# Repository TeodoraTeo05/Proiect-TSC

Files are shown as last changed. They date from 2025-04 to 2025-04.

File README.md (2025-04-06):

# Proiect TSC 2025 – OpenBook

## Descriere generală

OpenBook este un dispozitiv portabil de tip e-book reader bazat pe ESP32-C6. Dispozitivul conține un ecran e-paper, butoane de control, senzor de mediu, ceas de timp real și posibilitate de alimentare de la baterie Li-Po, fiind gândit ca un sistem eficient energetic și scalabil.
---

#### 1 Diagramă bloc

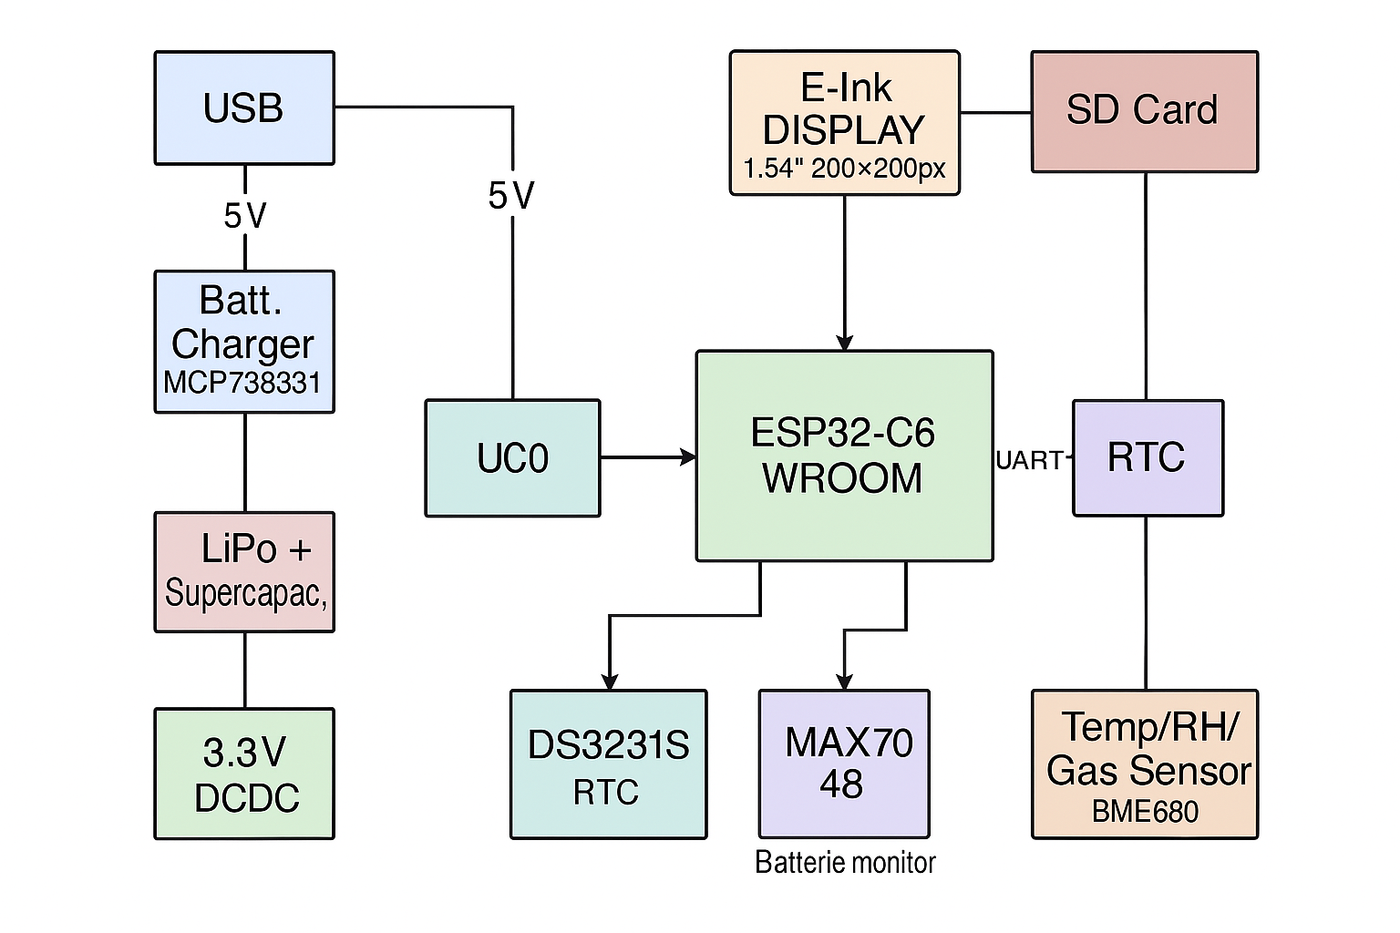
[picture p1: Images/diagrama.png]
Diagramă bloc


---
## 2 BOM (Bill of Materials)

| Part | Device | Datasheet |
|---|---|---|
| CHG_LED | ADAFRUIT_LEDCHIP-LED0603 | [ADAFRUIT_LEDCHIP-LED0603](N/A) |
| SJ1 | SJ | [SJ](N/A) |
| EPD_C5 | EAGLE-LTSPICE_CC0402 | [EAGLE-LTSPICE_CC0402](N/A) |
| R3 | ESP32_WROVER_EAGLE-LTSPICE_RR0402 | [ESP32_WROVER_EAGLE-LTSPICE_RR0402](N/A) |
| R1_PWRUSB | ESP32_WROVER_EAGLE-LTSPICE_RR0402 | [ESP32_WROVER_EAGLE-LTSPICE_RR0402](N/A) |
| C4_USB | EAGLE-LTSPICE_CC0402 | [EAGLE-LTSPICE_CC0402](N/A) |
| C1, C2, C6, C8, C9, C10, C_DELAY | ESP32_WROVER_EAGLE-LTSPICE_CC0402 | [ESP32_WROVER_EAGLE-LTSPICE_CC0402](N/A) |
| C3 | RCL_CPOL-EUCT3528 | [RCL_CPOL-EUCT3528](N/A) |
| R1, R1_PINH, R1_PINH1, R2_PINH, R2_PINH1, R4, R5, R6, R7, R8, R9, R10, R_BOOT, R_CHANGE, R_CL1, R_RESET | ESP32_WROVER_EAGLE-LTSPICE_RR0402 | [ESP32_WROVER_EAGLE-LTSPICE_RR0402](N/A) |
| C7 | ESP32_WROVER_EAGLE-LTSPICE_CC0402 | [ESP32_WROVER_EAGLE-LTSPICE_CC0402](N/A) |
| J4 | 112A-TAAR-R03_ATTEND | [112A-TAAR-R03_ATTEND](N/A) |
| R_CAPACITOR | ESP32_WROVER_EAGLE-LTSPICE_RR0402 | [ESP32_WROVER_EAGLE-LTSPICE_RR0402](N/A) |
| C5 | ESP32_WROVER_EAGLE-LTSPICE_CC0402 | [ESP32_WROVER_EAGLE-LTSPICE_CC0402](N/A) |
| EPD_C6, EPD_C7, EPD_C8, EPD_C9, EPD_C10, EPD_C11, EPD_C12 | EAGLE-LTSPICE_CC0402 | [EAGLE-LTSPICE_CC0402](N/A) |
| EPD_C1, EPD_C2 | ESP32_WROVER_EAGLE-LTSPICE_CC0402 | [ESP32_WROVER_EAGLE-LTSPICE_CC0402](N/A) |
| R2 | ESP32_WROVER_EAGLE-LTSPICE_RR0402 | [ESP32_WROVER_EAGLE-LTSPICE_RR0402](N/A) |
| R1_BAT | ESP32_WROVER_EAGLE-LTSPICE_RR0402 | [ESP32_WROVER_EAGLE-LTSPICE_RR0402](N/A) |
| Q1, Q2 | ESP32_WROVER_SPARKFUN-DISCRETESEMI_MOSFET_PCH-DMG2305UX-7 | [ESP32_WROVER_SPARKFUN-DISCRETESEMI_MOSFET_PCH-DMG2305UX-7](N/A) |
| R2_BAT | ESP32_WROVER_EAGLE-LTSPICE_RR0402 | [ESP32_WROVER_EAGLE-LTSPICE_RR0402](N/A) |
| C5_USB | EAGLE-LTSPICE_CC0402 | [EAGLE-LTSPICE_CC0402](N/A) |
| C1_BAT, C1_BAT1, C1_BAT2, C2_BAT | ESP32_WROVER_EAGLE-LTSPICE_CC0402 | [ESP32_WROVER_EAGLE-LTSPICE_CC0402](N/A) |
| C4 | ESP32_WROVER_EAGLE-LTSPICE_CC0402 | [ESP32_WROVER_EAGLE-LTSPICE_CC0402](N/A) |
| R2-USB, R2-USB1 | ESP32_WROVER_EAGLE-LTSPICE_RR0402 | [ESP32_WROVER_EAGLE-LTSPICE_RR0402](N/A) |
| L1 | 744043680IND_4828-WE-TPC_WRE | [744043680IND_4828-WE-TPC_WRE](N/A) |
| IC1 | BD5229G-TR | [BD5229G-TR](N/A) |
| SENSOR2 | ESP32_WROVER_BME680_BME680 | [ESP32_WROVER_BME680_BME680](N/A) |
| U$2 | BUTTON_CUSYOMV1 | [BUTTON_CUSYOMV1](N/A) |
| U$3 | BUTTON_CUSYOMV1 | [BUTTON_CUSYOMV1](N/A) |
| C10_SUPERCAP | CPH3225A | [CPH3225A](https://www.snapeda.com/parts/CPH3225A/Seiko+Instruments/view-part/?ref=snap) |
| U3 | DS3231SN# | [DS3231SN#](https://www.snapeda.com/parts/DS3231SN%23/Analog+Devices/view-part/?ref=snap) |
| U2 | ESP32-C6-WROOM-1-N8 | [ESP32-C6-WROOM-1-N8](N/A) |
| PFMF.050.1 | ESP32C6_VARISTORCN1812 | [ESP32C6_VARISTORCN1812](N/A) |
| D2, D7 | ESP32_WROVER_AVX---SD0805S020S1R0_AVX_SD0805S020S1R0_0_0AVX_SD0805S020S1R0_0_0 | [ESP32_WROVER_AVX---SD0805S020S1R0_AVX_SD0805S020S1R0_0_0AVX_SD0805S020S1R0_0_0](N/A) |
| MCP73831 | ESP32_WROVER_SPARKFUN-IC-POWER_MCP73831 | [ESP32_WROVER_SPARKFUN-IC-POWER_MCP73831](N/A) |
| J1 | FH34SRJ-24S-0.5SH_99_ | [FH34SRJ-24S-0.5SH_99_](N/A) |
| U4 | MAX17048G+T10 | [MAX17048G+T10](https://www.snapeda.com/parts/MAX17048G+T10/Analog+Devices/view-part/?ref=snap) |
| D3, D4, D5 | MBR0530 | [MBR0530](https://www.snapeda.com/parts/MBR0530/Onsemi/view-part/?ref=snap) |
| D6, D8, D9, D10, D11, D12 | PGB1010603MR | [PGB1010603MR](https://www.snapeda.com/parts/PGB1010603MR/Littelfuse/view-part/?ref=snap) |
| J3 | QWIIC_CONNECTORJS-1MM | [QWIIC_CONNECTORJS-1MM](N/A) |
| U$1 | BUTTON_CUSYOMV1 | [BUTTON_CUSYOMV1](N/A) |
| J2 | SAMACSYS_PARTS_USB4110-GF-A | [SAMACSYS_PARTS_USB4110-GF-A](N/A) |
| Q3 | SI1308EDL-T1-GE3 | [SI1308EDL-T1-GE3](N/A) |
| TP1, TP2, TP3, TP4, TP5, TP6, TP7, TP8, TP9, TP10, TP11, TP12, TP13, TP14, TP15, TP16, TP17 | TPTP20R | [facut de mine] |
| D1 | USBLC6-2SC6Y | [USBLC6-2SC6Y](https://www.snapeda.com/parts/USBLC6-2SC6Y/STMicroelectronics/view-part/?ref=snap) |
| U1 | W25Q512JVEIQ | [W25Q512JVEIQ](https://www.snapeda.com/parts/W25Q512JVEIQ/Winbond+Electronics/view-part/?ref=snap) |
| IC4 | XC6220A331MR-G | [XC6220A331MR-G](N/A) |

## 3. Funcționalitate hardware

Proiectul OpenBook este un cititor de tip e-paper, alimentat din baterie LiPo și construit în jurul microcontrollerului ESP32-C3-WROOM. 
Dispozitivul colectează date de mediu (temperatură, umiditate, CO2, particule), le salvează pe card microSD și le poate afișa pe ecranul e-paper.

### ESP32-C3-WROOM
- Modulul principal cu conectivitate Wi-Fi/BLE, capabil să comunice prin SPI, I2C și UART.
- Tensiune de alimentare: 3.3V, furnizată de LDO.

### Sistem de alimentare
- **USB-C** este utilizat pentru încărcare și comunicare USB.
- **MCP73832** gestionează încărcarea bateriei LiPo.
- **LDO 3.3V** alimentează ESP32 și restul componentelor la 3.3V.
- **DC/DC 5V** generează 5V pentru senzorii care necesită tensiune mai mare (PM și CO2).

### Senzori
- **BME680** - senzor de temperatură, umiditate și gaze, comunică prin I2C.
- **MH-Z19B** - senzor de CO2 alimentat la 5V, comunică prin UART.
- **PMSA003** - senzor pentru particule fine (PM2.5), comunică prin UART, 5V.

### Afișaj
- Display e-paper monocrom de 1.5" cu rezoluție 200x200 px.
- Interfață SPI comună cu SD Card-ul.

### SD Card
- Modul pentru stocarea datelor colectate sau a fișierelor text.
- Interfață SPI.

### Butoane
- 3 butoane tactile conectate la GPIO pentru control interfață (ex. navigare meniu, refresh ecran).

### Calcule de consum estimativ (valori medii)

| Modul | Tensiune | Curent (mA) | Consum estimativ |
|---|---|---|---|
| ESP32-C3 | 3.3V | 80-150 | 0.3-0.5W |
| E-Ink Display | 3.3V | 10 (refresh) | 0.03W |
| BME680 | 3.3V | 2-3 | 0.01W |
| MH-Z19B | 5V | 40-50 | 0.25W |
| PMSA003 | 5V | 60-100 | 0.5W |
| SD Card | 3.3V | 10 | 0.03W |
| MCP73832 (charger) | 5V | 1000 (max) | doar când încarcă |

**Modul deep sleep:** Consum sub 1 mA total. Ideal pentru dispozitiv portabil.

## 4. Pinout ESP32-C3

| Pin ESP32-C3 | Componentă | Motiv / Semnal |
|---|---|---|
| GPIO1 (I2C SDA)  | BME680 | Comunicație I2C |
| GPIO2 (I2C SCL)  | BME680 | Comunicație I2C |
| GPIO3 (UART RX)  | PMSA003 | UART RX senzor PM |
| GPIO4 (SPI CS SD)| SD Card | Chip Select SD Card |
| GPIO5 | E-Ink DC | Date/Command E-Ink |
| GPIO6 (SPI CLK)  | E-Ink & SD | Clock SPI |
| GPIO7 (SPI MOSI) | E-Ink & SD | Date SPI |
| GPIO8 (GPIO) | Buton 1 | Control meniu / page flip |
| GPIO9 (GPIO) | Buton 2 | Control meniu / page flip |
| GPIO10 (SPI CS)  | E-Ink Display | Chip Select e-paper |
| GPIO11 (SPI CS)  | Flash extern (opțional) | N/A |
| GPIO12 (USB D-)  | USB | Comunicație USB |
| GPIO13 (USB D+)  | USB | Comunicație USB |
| GPIO18 | MH-Z19B (UART TX) | UART pentru senzor CO2 |
| GPIO19 | Buton 3 | Navigare / confirmare |

## 5. Alte aspecte relevante

- Designul PCB respectă recomandările de trasee de putere (min 0.3mm), semnale (min 0.15mm).
- Antena ESP32-C3 este amplasată spre exteriorul plăcii, iar zona de sub ea este decupată.
- Condensatoarele de decuplare sunt apropiate de VCC-ul componentelor.
- Plan de masă solid pe ambele layere și via stitching activ.
- Toate componentele pasive sunt SMD 0402.
- Layout-ul este proiectat în Fusion360, aliniat cu dimensiunile carcasei fizice.
- Imaginile randate ale dispozitivului și carcasei se găsesc în folderul `Images/` din acest repository.

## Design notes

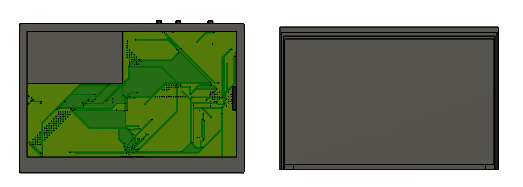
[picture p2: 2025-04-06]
Images/componente.png

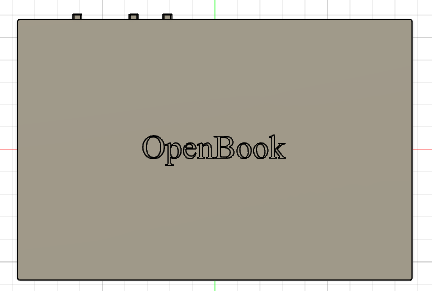
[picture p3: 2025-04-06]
Images/carcasa.png

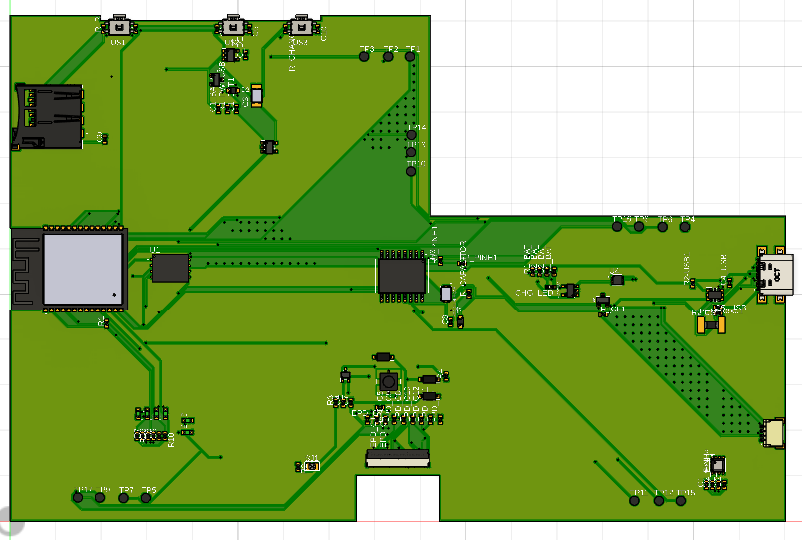
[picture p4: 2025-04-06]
Images/pcb.png

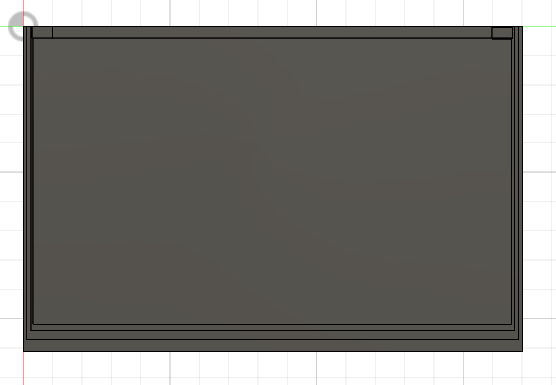
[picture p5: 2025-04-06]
Images/display.png

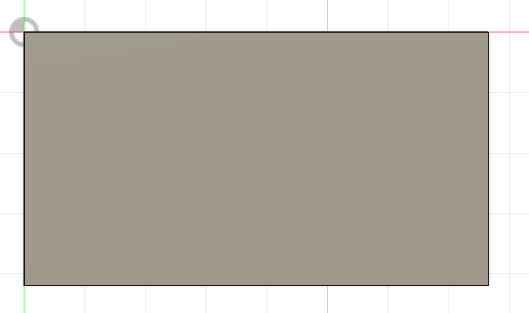
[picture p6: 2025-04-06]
Images/baterie.png

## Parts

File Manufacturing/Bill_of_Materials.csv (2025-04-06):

Qty | Value | Device | Package | Parts | Description | ARROW_PART_NUMBER | ARROW_PRICE-STOCK | AVAILABILITY | CENTROID_NOT_SPECIFIED | CHECK_PRICES | COPYRIGHT | DATASHEET | DESCRIPTION | DIGIKEY_DESCRIPTION | DIGIKEY_PART_NUMBER | HEIGHT | LEAD_FREE | MANUFACTURER_NAME | MANUFACTURER_PART_NUMBER | MF | MFR_NAME | MOUSER_PART_NUMBER | MOUSER_PRICE-STOCK | MOUSER_TESTING_PART_NUMBER | MOUSER_TESTING_PRICE-STOCK | MP | MPN | PACKAGE | POPULARITY | PREFIX | PRICE | PROD_ID | PURCHASE-URL | ROHS | SNAPEDA_LINK | SPICEMODEL | SPICEPREFIX | TEMPERATURE_RANGE_HIGH | TEMPERATURE_RANGE_LOW | TP_SIGNAL_NAME | VALUE
1 |  | ADAFRUIT_LEDCHIP-LED0603 | ADAFRUIT_CHIP-LED0603 | CHG_LED | LED
1 |  | SJ | SJ | SJ1 | SMD solder JUMPER |  |  |  |  |  |  |  |  |  |  |  |  |  |  |  |  |  |  |  |  |  |  |  | 3
1 | 0.1uF/50V | EAGLE-LTSPICE_CC0402 | EAGLE-LTSPICE_C0402 | EPD_C5 | CAPACITOR, European symbol |  |  |  |  |  |  |  |  |  |  |  |  |  |  |  |  |  |  |  |  |  |  |  |  |  |  |  |  |  |  | NONE | C
1 | 0.47 | ESP32_WROVER_EAGLE-LTSPICE_RR0402 | ESP32_WROVER_EAGLE-LTSPICE_R0402 | R3 | RESISTOR, European symbol |  |  |  |  |  |  |  |  |  |  |  |  |  |  |  |  |  |  |  |  |  |  |  |  |  |  |  |  |  |  | NONE | R
1 | 100k | ESP32_WROVER_EAGLE-LTSPICE_RR0402 | ESP32_WROVER_EAGLE-LTSPICE_R0402 | R1_PWRUSB | RESISTOR, European symbol |  |  |  |  |  |  |  |  |  |  |  |  |  |  |  |  |  |  |  |  |  |  |  |  |  |  |  |  |  |  | NONE | R
1 | 100nF | EAGLE-LTSPICE_CC0402 | EAGLE-LTSPICE_C0402 | C4_USB | CAPACITOR, European symbol |  |  |  |  |  |  |  |  |  |  |  |  |  |  |  |  |  |  |  |  |  |  |  |  |  |  |  |  |  |  | NONE | C
7 | 100nF | ESP32_WROVER_EAGLE-LTSPICE_CC0402 | ESP32_WROVER_EAGLE-LTSPICE_C0402 | C1, C2, C6, C8, C9, C10, C_DELAY | CAPACITOR, European symbol |  |  |  |  |  |  |  |  |  |  |  |  |  |  |  |  |  |  |  |  |  |  |  |  |  |  |  |  |  |  | NONE | C
1 | 100uF TANT | RCL_CPOL-EUCT3528 | RCL_CT3528 | C3 | POLARIZED CAPACITOR, European symbol |  |  |  |  |  |  |  |  |  |  |  |  |  |  |  |  |  |  |  |  |  |  |  | 0 |  |  |  |  |  |  |  | C
16 | 10k | ESP32_WROVER_EAGLE-LTSPICE_RR0402 | ESP32_WROVER_EAGLE-LTSPICE_R0402 | R1, R1_PINH, R1_PINH1, R2_PINH, R2_PINH1, R4, R5, R6, R7, R8, R9, R10, R_BOOT, R_CHANGE, R_CL1, R_RESET | RESISTOR, European symbol |  |  |  |  |  |  |  |  |  |  |  |  |  |  |  |  |  |  |  |  |  |  |  |  |  |  |  |  |  |  | NONE | R
1 | 10uF | ESP32_WROVER_EAGLE-LTSPICE_CC0402 | ESP32_WROVER_EAGLE-LTSPICE_C0402 | C7 | CAPACITOR, European symbol |  |  |  |  |  |  |  |  |  |  |  |  |  |  |  |  |  |  |  |  |  |  |  |  |  |  |  |  |  |  | NONE | C
1 | 112A-TAAR-R03_ATTEND | 112A-TAAR-R03_ATTEND | 112ATAARR03ATTEND | J4 | Micro SD Card Socket, Push-Push Type, Top Mount, SMT, H=1.83mm, 10u |  |  |  |  |  |  |  | Micro SD Card Socket | Push-Push Type | Top Mount | SMT | H=1.83mm | 10u |  |  | 1.9mm |  | ATTEND | 112A-TAAR-R03 ATTEND
1 | 15 | ESP32_WROVER_EAGLE-LTSPICE_RR0402 | ESP32_WROVER_EAGLE-LTSPICE_R0402 | R_CAPACITOR | RESISTOR, European symbol |  |  |  |  |  |  |  |  |  |  |  |  |  |  |  |  |  |  |  |  |  |  |  |  |  |  |  |  |  |  | NONE | R
1 | 1uF | ESP32_WROVER_EAGLE-LTSPICE_CC0402 | ESP32_WROVER_EAGLE-LTSPICE_C0402 | C5 | CAPACITOR, European symbol |  |  |  |  |  |  |  |  |  |  |  |  |  |  |  |  |  |  |  |  |  |  |  |  |  |  |  |  |  |  | NONE | C
7 | 1uF/50V | EAGLE-LTSPICE_CC0402 | EAGLE-LTSPICE_C0402 | EPD_C6, EPD_C7, EPD_C8, EPD_C9, EPD_C10, EPD_C11, EPD_C12 | CAPACITOR, European symbol |  |  |  |  |  |  |  |  |  |  |  |  |  |  |  |  |  |  |  |  |  |  |  |  |  |  |  |  |  |  | NONE | C
2 | 1uF/50V | ESP32_WROVER_EAGLE-LTSPICE_CC0402 | ESP32_WROVER_EAGLE-LTSPICE_C0402 | EPD_C1, EPD_C2 | CAPACITOR, European symbol |  |  |  |  |  |  |  |  |  |  |  |  |  |  |  |  |  |  |  |  |  |  |  |  |  |  |  |  |  |  | NONE | C
1 | 2.2 | ESP32_WROVER_EAGLE-LTSPICE_RR0402 | ESP32_WROVER_EAGLE-LTSPICE_R0402 | R2 | RESISTOR, European symbol |  |  |  |  |  |  |  |  |  |  |  |  |  |  |  |  |  |  |  |  |  |  |  |  |  |  |  |  |  |  | NONE | R
1 | 200 | ESP32_WROVER_EAGLE-LTSPICE_RR0402 | ESP32_WROVER_EAGLE-LTSPICE_R0402 | R1_BAT | RESISTOR, European symbol |  |  |  |  |  |  |  |  |  |  |  |  |  |  |  |  |  |  |  |  |  |  |  |  |  |  |  |  |  |  | NONE | R
2 | 20V/4.2A/52m?/1.4W | ESP32_WROVER_SPARKFUN-DISCRETESEMI_MOSFET_PCH-DMG2305UX-7 | ESP32_WROVER_SPARKFUN-DISCRETESEMI_SOT23-3 | Q1, Q2 | P-channel MOSFETs |  |  |  |  |  |  |  |  |  |  |  |  |  |  |  |  |  |  |  |  |  |  |  |  |  |  | TRAN-14388 |  |  |  |  |  |  |  |  | 20V/4.2A/52m?/1.4W
1 | 2k | ESP32_WROVER_EAGLE-LTSPICE_RR0402 | ESP32_WROVER_EAGLE-LTSPICE_R0402 | R2_BAT | RESISTOR, European symbol |  |  |  |  |  |  |  |  |  |  |  |  |  |  |  |  |  |  |  |  |  |  |  |  |  |  |  |  |  |  | NONE | R
1 | 4.7uF | EAGLE-LTSPICE_CC0402 | EAGLE-LTSPICE_C0402 | C5_USB | CAPACITOR, European symbol |  |  |  |  |  |  |  |  |  |  |  |  |  |  |  |  |  |  |  |  |  |  |  |  |  |  |  |  |  |  | NONE | C
4 | 4.7uF | ESP32_WROVER_EAGLE-LTSPICE_CC0402 | ESP32_WROVER_EAGLE-LTSPICE_C0402 | C1_BAT, C1_BAT1, C1_BAT2, C2_BAT | CAPACITOR, European symbol |  |  |  |  |  |  |  |  |  |  |  |  |  |  |  |  |  |  |  |  |  |  |  |  |  |  |  |  |  |  | NONE | C
1 | 4.7uF/25V | ESP32_WROVER_EAGLE-LTSPICE_CC0402 | ESP32_WROVER_EAGLE-LTSPICE_C0402 | C4 | CAPACITOR, European symbol |  |  |  |  |  |  |  |  |  |  |  |  |  |  |  |  |  |  |  |  |  |  |  |  |  |  |  |  |  |  | NONE | C
2 | 5k1 | ESP32_WROVER_EAGLE-LTSPICE_RR0402 | ESP32_WROVER_EAGLE-LTSPICE_R0402 | R2-USB, R2-USB1 | RESISTOR, European symbol |  |  |  |  |  |  |  |  |  |  |  |  |  |  |  |  |  |  |  |  |  |  |  |  |  |  |  |  |  |  | NONE | R
1 | 68uH | 744043680IND_4828-WE-TPC_WRE | IND_4828-WE-TPC_WRE | L1 |  |  |  |  |  |  | Copyright (C) 2024 Ultra Librarian. All rights reserved. |  |  |  |  |  |  |  | 744043680 |  | Wurth Electronics
1 | BD5229G-TR | BD5229G-TR | SOT95P280X125-5N | IC1 | Voltage Detector with Adjustable Delay Time: CMOS processes are utilized to develop high precision, low current consumption CMOS reset ICs that allow arbitrary setting of the delay time. The extensive lineup includes both Nch Open Drain and CMOS output types in a wide range of detection voltages (from 2.3V to 6.0V, in 0.1V steps), enabling selection of the ideal solution based on customer requirements. In addition, the entire series is of course both lead-free and RoHS-compliant. |  |  |  |  |  |  |  | Voltage Detector with Adjustable Delay Time: CMOS processes are utilized to develop high precision | low current consumption CMOS reset ICs that allow arbitrary setting of the delay time. The extensive lineup includes both Nch Open Drain and CMOS output types in a wide range of detection voltages (from 2.3V to 6.0V | in 0.1V steps) | enabling selection of the ideal solution based on customer requirements. In addition | the entire series is of course both lead-free and RoHS-compliant. |  |  | 1.25mm |  | ROHM Semiconductor | BD5229G-TR |  |  | 755-BD5229G-TR | https://www.mouser.co.uk/ProductDetail/ROHM-Semiconductor/BD5229G-TR?qs=4kLU8WoGk0vvnhrrYwdszw%3D%3D
1 | BME688 | ESP32_WROVER_BME680_BME680 | ESP32_WROVER_BME680_PSON80P300X300X100-8N | SENSOR2 | Integrated Environmental Unit |  |  | Unavailable |  |  |  |  | Integrated Environmental Unit |  |  |  |  |  |  | Bosch Sensortec |  |  |  |  |  | BME680 |  | LGA-8 Bosch Tools |  |  | None
1 | BOOT_BUTTON | BUTTON_CUSYOMV1 | MYBUTTON | U$2
1 | CHANGE_BUTTON | BUTTON_CUSYOMV1 | MYBUTTON | U$3
1 | CPH3225A | CPH3225A | CAPCP3225X100N | C10_SUPERCAP | Cap 0.011F 3.3V 1210 Flat Check availability |  |  | Not in stock |  | https://www.snapeda.com/parts/CPH3225A/Seiko+Instruments/view-part/?ref=eda |  |  | 11 mF (EDLC) Supercapacitor 3.3 V 1210 (3225 Metric) - - |  |  |  |  |  |  | Seiko Instruments |  |  |  |  |  | CPH3225A |  | 1210 Seiko |  |  | None |  | https://www.snapeda.com/api/url_track_click_mouser/?unipart_id=562593&manufacturer=Seiko Instruments&part_name=CPH3225A&search_term=None |  | https://www.snapeda.com/parts/CPH3225A/Seiko+Instruments/view-part/?ref=snap
1 | DS3231SN# | DS3231SN# | SOIC127P1032X265-16N | U3 | Real Time Clock Serial 16-Pin SOIC W T/R Check availability |  |  | In Stock |  | https://www.snapeda.com/parts/DS3231SN%23/Analog+Devices/view-part/?ref=eda |  |  | Extremely Accurate I2C-Integrated RTC/TCXO/Crystal |  |  |  |  |  |  | Analog Devices |  |  |  |  |  | DS3231SN# |  | SOIC-16 Maxim |  |  | None |  | https://www.snapeda.com/api/url_track_click_mouser/?unipart_id=99048&manufacturer=Analog Devices&part_name=DS3231SN#&search_term=None |  | https://www.snapeda.com/parts/DS3231SN%23/Analog+Devices/view-part/?ref=snap
1 | ESP32-C6-WROOM-1-N8 | ESP32-C6-WROOM-1-N8 | XCVR_ESP32-C6-WROOM-1-N8 | U2 | Check availability |  |  | In Stock |  | https://www.snapeda.com/parts/ESP32-C6-WROOM-1-N8/Espressif+Systems/view-part/?ref=eda |  |  | Multiprotocol Modules ESP32-C6 module | Wi-Fi 6 in 2.4 GHz band | Bluetooth 5 | Zigbee 3.0 and Thread. ESP34-WROOM Compatible - ENGINEERING SAMPLE |  |  |  |  |  |  | Espressif Systems |  |  |  |  |  | ESP32-C6-WROOM-1-N8 |  | None |  |  | None |  |  |  | https://www.snapeda.com/parts/ESP32-C6-WROOM-1-N8/Espressif+Systems/view-part/?ref=snap
1 | ESP32C6_VARISTORCN1812 | ESP32C6_VARISTORCN1812 | ESP32C6_VARISTOR_CT/CN1812 | PFMF.050.1 | VARISTOR |  |  |  |  |  |  |  |  |  |  |  |  |  |  |  |  |  |  |  |  |  |  |  | 0
2 | ESP32_WROVER_AVX---SD0805S020S1R0_AVX_SD0805S020S1R0_0_0AVX_SD0805S020S1R0_0_0 | ESP32_WROVER_AVX---SD0805S020S1R0_AVX_SD0805S020S1R0_0_0AVX_SD0805S020S1R0_0_0 | ESP32_WROVER_AVX---SD0805S020S1R0_AVX_SD0805S020S1R0_0 | D2, D7 | Schottky Barrier Rectifier Diode |  |  |  | No |  |  | http://datasheets.avx.com/schottky.pdf |  | DIODE SCHOTTKY 20V 1A 0805 | 478-7800-1-ND |  | yes |  |  | AVX |  | 581-SD0805S020S1R0 |  |  |  |  |  | 0805 (2012 metric) |  | D |  |  |  | yes |  |  |  | +125°C | -55°C
1 | ESP32_WROVER_SPARKFUN-IC-POWER_MCP73831 | ESP32_WROVER_SPARKFUN-IC-POWER_MCP73831 | ESP32_WROVER_SPARKFUN-IC-POWER_SOT23-5 | MCP73831 | MCP73831T Li-Ion, Li-Pol Controller |  |  |  |  |  |  |  |  |  |  |  |  |  |  |  |  |  |  |  |  |  |  |  |  |  |  | IC-09995
1 | FH34SRJ-24S-0.5SH_99_ | FH34SRJ-24S-0.5SH_99_ | FH34SRJ24S05SH99 | J1 | (0.50mm) Surface Mount, Right Angle |  |  |  |  |  |  |  | 24 Position FFC | FPC Connector Contacts | (0.50mm) Surface Mount | Right Angle |  |  | 1.1mm |  | Hirose | FH34SRJ-24S-0.5SH(99) |  |  | 798-FH34SRJ24S05SH99 | https://www.mouser.co.uk/ProductDetail/Hirose-Connector/FH34SRJ-24S-0.5SH99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
1 | MAX17048G+T10 | MAX17048G+T10 | SON50P200X200X80-9N | U4 | Check availability |  |  | In Stock |  | https://www.snapeda.com/parts/MAX17048G+T10/Analog+Devices/view-part/?ref=eda |  |  | 3µA 1-Cell/2-Cell Fuel Gauge with ModelGauge |  |  |  |  |  |  | Analog Devices |  |  |  |  |  | MAX17048G+T10 |  | TDFN-8 Maxim |  |  | None |  | https://www.snapeda.com/api/url_track_click_mouser/?unipart_id=329239&manufacturer=Analog Devices&part_name=MAX17048G+T10&search_term=None |  | https://www.snapeda.com/parts/MAX17048G+T10/Analog+Devices/view-part/?ref=snap
3 | MBR0530 | MBR0530 | SOD3716X135N | D3, D4, D5 | ON SEMICONDUCTOR - MBR0530 - DIODE, SCHOTTKY, 0.5A, 30V, SOD-123 |  |  | In Stock |  | https://www.snapeda.com/parts/MBR0530/Onsemi/view-part/?ref=eda |  |  | Diode Schottky 30 V 500mA Surface Mount SOD-123 |  |  |  |  |  |  | ON Semiconductor |  |  |  |  |  | MBR0530 |  | SOD-123-2 ON Semiconductor |  |  | None |  | https://www.snapeda.com/api/url_track_click_mouser/?unipart_id=179458&manufacturer=ON Semiconductor&part_name=MBR0530&search_term=None |  | https://www.snapeda.com/parts/MBR0530/Onsemi/view-part/?ref=snap
6 | PGB1010603MR | PGB1010603MR | DIOC1608X36N | D6, D8, D9, D10, D11, D12 | Check availability |  |  | In Stock |  | https://www.snapeda.com/parts/PGB1010603MR/Littelfuse/view-part/?ref=eda |  |  | 150V (Typ) Clamp - Ipp Tvs Diode Surface Mount 0603 (1608 Metric) |  |  |  |  |  |  | Littelfuse Inc. |  |  |  |  |  | PGB1010603MR |  | 0603 Littelfuse Inc. |  |  | None |  | https://www.snapeda.com/api/url_track_click_mouser/?unipart_id=5659453&manufacturer=Littelfuse Inc.&part_name=PGB1010603MR&search_term=None |  | https://www.snapeda.com/parts/PGB1010603MR/Littelfuse/view-part/?ref=snap
1 | QWIIC_RIGHT_ANGLE | QWIIC_CONNECTORJS-1MM | JST04_1MM_RA | J3 | SparkFun I2C Standard Qwiic Connector |  |  |  |  |  |  |  |  |  |  |  |  |  |  |  |  |  |  |  |  |  |  |  |  |  |  | CONN-13694 |  |  |  |  |  |  |  |  | QWIIC_RIGHT_ANGLE
1 | RESET_BUTTON | BUTTON_CUSYOMV1 | MYBUTTON | U$1
1 | SAMACSYS_PARTS_USB4110-GF-A | SAMACSYS_PARTS_USB4110-GF-A | SAMACSYS_PARTS_USB4110GFA | J2 | CONN USB 2.0 TYPE-C R/A SMT |  |  |  |  |  |  |  | CONN USB 2.0 TYPE-C R/A SMT |  |  | 3.26mm |  | GCT (GLOBAL CONNECTOR TECHNOLOGY) | USB4110-GF-A |  |  | 640-USB4110-GF-A | https://www.mouser.co.uk/ProductDetail/GCT/USB4110-GF-A?qs=KUoIvG%2F9IlYiZvIXQjyJeA%3D%3D
1 | SI1308EDL-T1-GE3 | SI1308EDL-T1-GE3 | SOT65P210X110-3N | Q3 | MOSFET N-Ch 30V 1.5A TrenchFET SC70 Vishay Si1308EDL-T1-GE3 N-channel MOSFET Transistor, 1.5 A, 30 V, 3-Pin SC-70 |  |  | In Stock |  | https://www.snapeda.com/parts/SI1308EDL-T1-GE3/Vishay+Siliconix/view-part/?ref=eda |  |  | Si1308EDL-T1-GE3 N-channel MOSFET Transistor | 1.5 A | 30 V | 3-Pin SC-70 | Siliconix / Vishay SI1308EDL-T1-GE3 |  |  |  |  |  |  | Vishay Siliconix |  |  |  |  |  | SI1308EDL-T1-GE3 |  | SOT-323 Vishay Semiconductor |  |  | None |  | https://www.snapeda.com/api/url_track_click_mouser/?unipart_id=274603&manufacturer=Vishay Siliconix&part_name=SI1308EDL-T1-GE3&search_term=None |  | https://www.snapeda.com/parts/SI1308EDL-T1-GE3/Vishay+Siliconix/view-part/?ref=snap
17 | TPTP20R | TPTP20R | TP20R | TP1, TP2, TP3, TP4, TP5, TP6, TP7, TP8, TP9, TP10, TP11, TP12, TP13, TP14, TP15, TP16, TP17 | Test pad |  |  |  |  |  |  |  |  |  |  |  |  |  |  |  |  |  |  |  |  |  |  |  | 2
1 | USBLC6-2SC6Y | USBLC6-2SC6Y | SOT95P280X145-6N | D1 | Low Cap. ESD Protection Auto SOT-23-6 STMicroelectronics USBLC6-2SC6Y, Dual Uni-Directional TVS Diode Array, 6-Pin SOT-23 |  |  | In Stock |  | https://www.snapeda.com/parts/USBLC6-2SC6Y/STMicroelectronics/view-part/?ref=eda |  |  | 17V Clamp 5A (8/20µs) Ipp Tvs Diode Surface Mount SOT-23-6 |  |  |  |  |  |  | STMicroelectronics |  |  |  |  |  | USBLC6-2SC6Y |  | SOT-23-6 STMicroelectronics |  |  | None |  |  |  | https://www.snapeda.com/parts/USBLC6-2SC6Y/STMicroelectronics/view-part/?ref=snap
1 | W25Q512JVEIQ | W25Q512JVEIQ | SON127P600X800X80-9N | U1 | Check availability |  |  | In Stock |  | https://www.snapeda.com/parts/W25Q512JVEIQ/Winbond+Electronics/view-part/?ref=eda |  |  | FLASH - NOR Memory IC 512Mb (64M x 8) SPI - Quad I/O 133 MHz 8-WSON (8x6) |  |  |  |  |  |  | Winbond Electronics |  |  |  |  |  | W25Q512JVEIQ |  | Package |  |  | None |  |  |  | https://www.snapeda.com/parts/W25Q512JVEIQ/Winbond+Electronics/view-part/?ref=snap
1 | XC6220A331MR-G | XC6220A331MR-G | SOT95P280X120-5N | IC4 | LDO Voltage Regulators |  |  |  |  |  |  |  | LDO Voltage Regulators |  |  | 1.2mm |  | Torex | XC6220A331MR-G |  |  | 865-XC6220A331MR-G | https://www.mouser.co.uk/ProductDetail/Torex-Semiconductor/XC6220A331MR-G?qs=AsjdqWjXhJ8ZSWznL1J0gg%3D%3D

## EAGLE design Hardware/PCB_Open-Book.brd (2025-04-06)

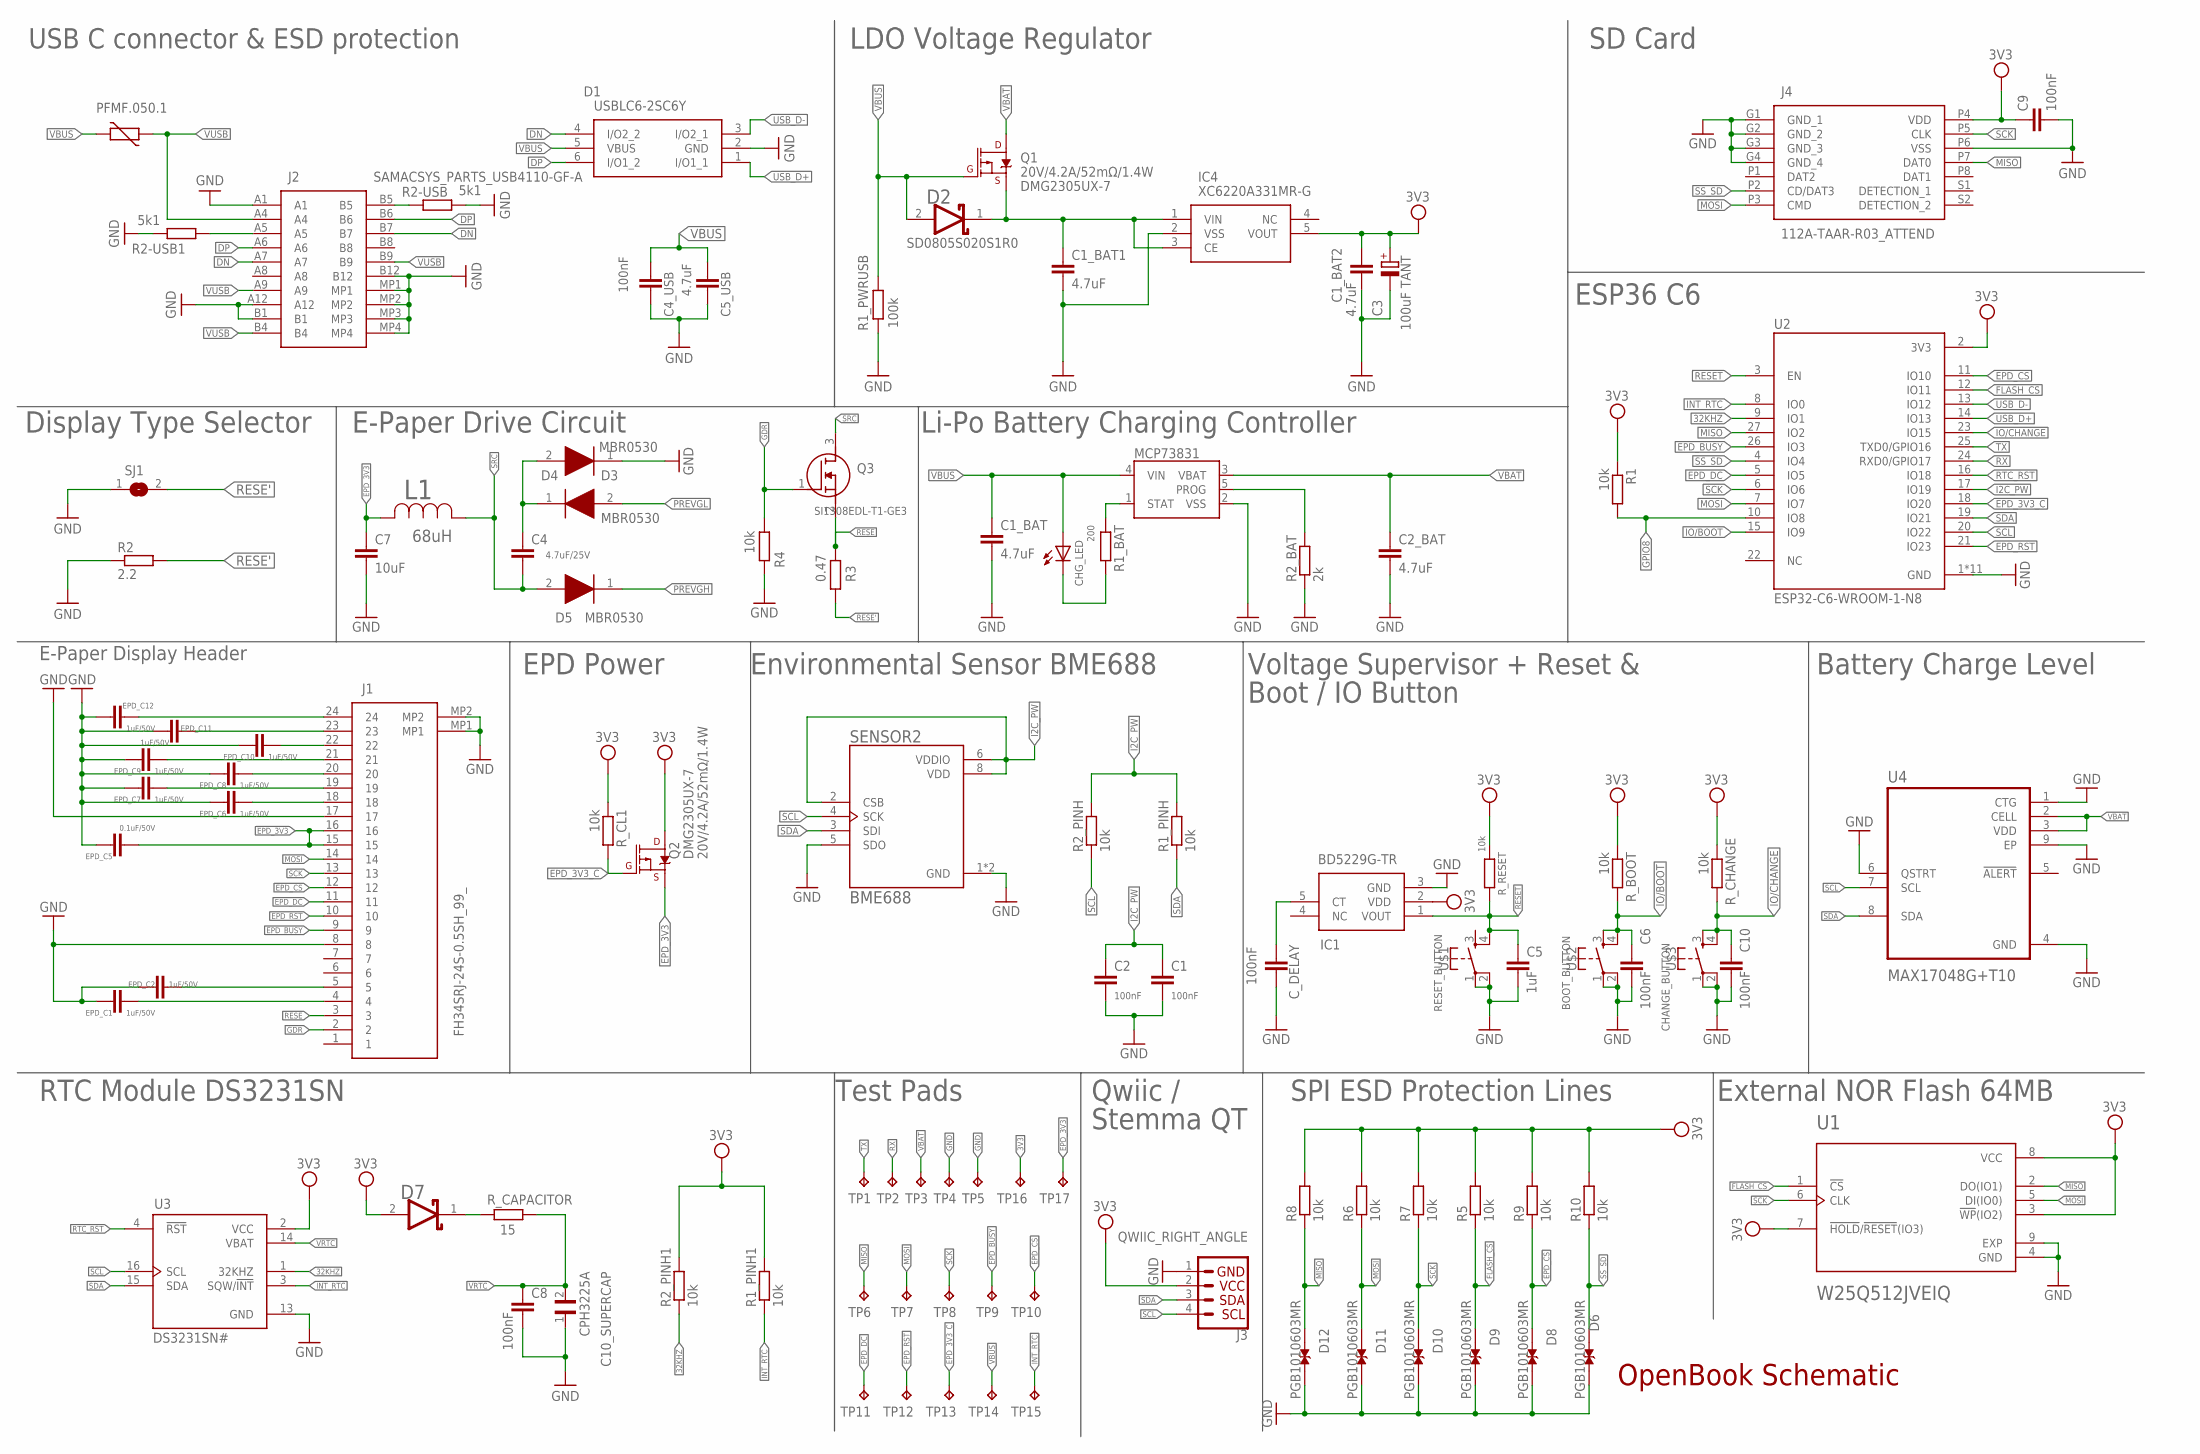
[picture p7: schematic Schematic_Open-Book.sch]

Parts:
C1, C2, C6, C8, C9, C10: 100nF; ESP32_WROVER_EAGLE-LTSPICE_C0402
C1_BAT, C1_BAT1, C1_BAT2, C2_BAT: 4.7uF; ESP32_WROVER_EAGLE-LTSPICE_C0402
C3: 100uF TANT; RCL_CT3528
C4: 4.7uF/25V; ESP32_WROVER_EAGLE-LTSPICE_C0402
C4_USB: 100nF; EAGLE-LTSPICE_C0402
C5: 1uF; ESP32_WROVER_EAGLE-LTSPICE_C0402
C5_USB: 4.7uF; EAGLE-LTSPICE_C0402
C7: 10uF; ESP32_WROVER_EAGLE-LTSPICE_C0402
C10_SUPERCAP: CPH3225A; CAPCP3225X100N
CHG_LED: ADAFRUIT_LEDCHIP-LED0603; ADAFRUIT_CHIP-LED0603
C_DELAY: 100nF; ESP32_WROVER_EAGLE-LTSPICE_C0402
D1: USBLC6-2SC6Y; SOT95P280X145-6N
D2, D7: ESP32_WROVER_AVX---SD0805S020S1R0_AVX_SD0805S020S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; ESP32_WROVER_AVX---SD0805S020S1R0_AVX_SD0805S020S1R0_0
D3, D4, D5: MBR0530; SOD3716X135N
D6, D8, D9, D10, D11, D12: PGB1010603MR; DIOC1608X36N
EPD_C1, EPD_C2: 1uF/50V; ESP32_WROVER_EAGLE-LTSPICE_C0402
EPD_C5: 0.1uF/50V; EAGLE-LTSPICE_C0402
EPD_C6, EPD_C7, EPD_C8, EPD_C9, EPD_C10, EPD_C11, EPD_C12: 1uF/50V; EAGLE-LTSPICE_C0402
IC1: BD5229G-TR; SOT95P280X125-5N
IC4: XC6220A331MR-G; SOT95P280X120-5N
J1: FH34SRJ-24S-0.5SH_99_; FH34SRJ24S05SH99
J2: SAMACSYS_PARTS_USB4110-GF-A; SAMACSYS_PARTS_USB4110GFA
J3: QWIIC_RIGHT_ANGLE; JST04_1MM_RA
J4: 112A-TAAR-R03_ATTEND; 112ATAARR03ATTEND
L1: 68uH; IND_4828-WE-TPC_WRE
MCP73831: ESP32_WROVER_SPARKFUN-IC-POWER_MCP73831; ESP32_WROVER_SPARKFUN-IC-POWER_SOT23-5
PFMF.050.1: ESP32C6_VARISTORCN1812; ESP32C6_VARISTOR_CT/CN1812
Q1, Q2: 20V/4.2A/52mΩ/1.4W; ESP32_WROVER_SPARKFUN-DISCRETESEMI_SOT23-3
Q3: SI1308EDL-T1-GE3; SOT65P210X110-3N
R1, R1_PINH, R1_PINH1, R2_PINH, R2_PINH1, R4, R5, R6, R7, R8, R9, R10: 10k; ESP32_WROVER_EAGLE-LTSPICE_R0402
R1_BAT: 200; ESP32_WROVER_EAGLE-LTSPICE_R0402
R1_PWRUSB: 100k; ESP32_WROVER_EAGLE-LTSPICE_R0402
R2: 2.2; ESP32_WROVER_EAGLE-LTSPICE_R0402
R2-USB, R2-USB1: 5k1; ESP32_WROVER_EAGLE-LTSPICE_R0402
R2_BAT: 2k; ESP32_WROVER_EAGLE-LTSPICE_R0402
R3: 0.47; ESP32_WROVER_EAGLE-LTSPICE_R0402
R_BOOT: 10k; ESP32_WROVER_EAGLE-LTSPICE_R0402
R_CAPACITOR: 15; ESP32_WROVER_EAGLE-LTSPICE_R0402
R_CHANGE: 10k; ESP32_WROVER_EAGLE-LTSPICE_R0402
R_CL1: 10k; ESP32_WROVER_EAGLE-LTSPICE_R0402
R_RESET: 10k; ESP32_WROVER_EAGLE-LTSPICE_R0402
SENSOR2: BME688; ESP32_WROVER_BME680_PSON80P300X300X100-8N
SJ1: SJ
TP1, TP2, TP3, TP4, TP5, TP6, TP7, TP8, TP9, TP10, TP11, TP12, TP13, TP14, TP15, TP16, TP17: TPTP20R; TP20R
U1: W25Q512JVEIQ; SON127P600X800X80-9N
U2: ESP32-C6-WROOM-1-N8; XCVR_ESP32-C6-WROOM-1-N8
U3: DS3231SN#; SOIC127P1032X265-16N
U4: MAX17048G+T10; SON50P200X200X80-9N
U$1: RESET_BUTTON; MYBUTTON
U$2: BOOT_BUTTON; MYBUTTON
U$3: CHANGE_BUTTON; MYBUTTON

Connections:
3V3: C1_BAT2.1, C3.+, C9.1, D7.2 (ANODE), IC1.2 (VDD), IC4.5 (VOUT), J3.2, J4.P4 (VDD), Q2.3 (D), R1.1, R1_PINH1.2, R2_PINH1.2, R5.2, R6.2, R7.2, R8.2, R9.2, R10.2, R_BOOT.1, R_CHANGE.1, R_CL1.1, R_RESET.1, TP16.TP, U1.3 (!WP!(IO2)), U1.7 (!HOLD!/!RESET!(IO3)), U1.8 (VCC), U2.2 (3V3), U3.2 (VCC)
32KHZ: R2_PINH1.1, U2.9 (IO1), U3.1 (32KHZ)
DN: D1.4 (I/O2_2), J2.A7, J2.B7
DP: D1.6 (I/O1_2), J2.A6, J2.B6
EPD_3V3: C7.1, EPD_C5.1, J1.15, J1.16, L1.2, Q2.2 (S), TP17.TP
EPD_3V3_C: Q2.1 (G), R_CL1.2, TP13.TP, U2.18 (IO20)
EPD_BUSY: J1.9, TP9.TP, U2.26 (IO3)
EPD_CS: D8.1, J1.12, R9.1, TP10.TP, U2.11 (IO10)
EPD_DC: J1.11, TP11.TP, U2.5 (IO5)
EPD_RST: J1.10, TP12.TP, U2.21 (IO23)
FLASH_CS: D9.1, R5.1, U1.1 (!CS), U2.12 (IO11)
GDR: J1.2, Q3.1 (G), R4.2
GND: C1.2, C1_BAT.2, C1_BAT1.2, C1_BAT2.2, C2.2, C2_BAT.2, C3.-, C4_USB.2, C5.2, C5_USB.2, C6.2, C7.2, C8.2, C9.2, C10.2, C10_SUPERCAP.1, C_DELAY.2, D1.2 (GND), D4.1 (K), D6.2, D8.2, D9.2, D10.2, D11.2, D12.2, EPD_C1.2, EPD_C2.2, EPD_C5.2, EPD_C6.2, EPD_C7.2, EPD_C8.2, EPD_C9.2, EPD_C10.2, EPD_C11.2, EPD_C12.2, IC1.3 (GND), IC4.2 (VSS), J1.8, J1.17, J1.MP1, J1.MP2, J2.A1, J2.A12, J2.B1, J2.B12, J2.MP1, J2.MP2, J2.MP3, J2.MP4, J3.1, J4.G1 (GND_1), J4.G2 (GND_2), J4.G3 (GND_3), J4.G4 (GND_4), J4.P6 (VSS), MCP73831.2 (VSS), R1_PWRUSB.2, R2.1, R2-USB.2, R2-USB1.1, R2_BAT.1, R4.1, SENSOR2.1 (GND), SENSOR2.5 (SDO), SENSOR2.7 (GND), SJ1.1, TP4.TP, TP5.TP, U1.4 (GND), U1.9 (EXP), U2.1 (GND), U2.28 (GND), U2.29_1 (GND), U2.29_2 (GND), U2.29_3 (GND), U2.29_4 (GND), U2.29_5 (GND), U2.29_6 (GND), U2.29_7 (GND), U2.29_8 (GND), U2.29_9 (GND), U3.13 (GND), U4.1 (CTG), U4.4 (GND), U4.6 (QSTRT), U4.9 (EP), U$1.1, U$1.2, U$2.1, U$2.2, U$3.1, U$3.2
GPIO8: R1.2, U2.10 (IO8)
I2C_PW: C1.1, C2.1, R1_PINH.2, R2_PINH.2, SENSOR2.2 (CSB), SENSOR2.6 (VDDIO), SENSOR2.8 (VDD), U2.17 (IO19)
INT_RTC: R1_PINH1.1, TP15.TP, U2.8 (IO0), U3.3 (SQW/!INT)
IO/BOOT: C6.1, R_BOOT.2, U2.15 (IO9), U$2.3, U$2.4
IO/CHANGE: C10.1, R_CHANGE.2, U2.23 (IO15), U$3.3, U$3.4
MISO: D12.1, J4.P7 (DAT0), R8.1, TP6.TP, U1.2 (DO(IO1)), U2.27 (IO2)
MOSI: D11.1, J1.14, J4.P3 (CMD), R6.1, TP7.TP, U1.5 (DI(IO0)), U2.7 (IO7)
unnamed: J2.B5, R2-USB.1
unnamed: J2.A5, R2-USB1.2
unnamed: C4.1, D3.1 (K), D4.2 (A)
unnamed: C1_BAT1.1, D2.1 (CATHODE), IC4.1 (VIN), IC4.3 (CE), Q1.2 (S)
unnamed: MCP73831.5 (PROG), R2_BAT.2
unnamed: CHG_LED.C, R1_BAT.2
unnamed: MCP73831.1 (STAT), R1_BAT.1
unnamed: C_DELAY.1, IC1.5 (CT)
unnamed: EPD_C2.1, J1.5
unnamed: EPD_C1.1, J1.4
unnamed: D7.1 (CATHODE), R_CAPACITOR.2
unnamed: EPD_C12.1, J1.24
unnamed: EPD_C11.1, J1.23
unnamed: EPD_C10.1, J1.22
unnamed: EPD_C8.1, J1.20
unnamed: EPD_C7.1, J1.19
unnamed: EPD_C9.1, J1.21
unnamed: EPD_C6.1, J1.18
PREVGH: D5.1 (K)
PREVGL: D3.2 (A)
RESE: J1.3, Q3.2 (S), R3.2
RESE': R2.2, R3.1, SJ1.2
RESET: C5.1, IC1.1 (VOUT), R_RESET.2, U2.3 (EN), U$1.4
RTC_RST: U2.16 (IO18), U3.4 (!RST)
RX: TP2.TP, U2.24 (RXD0/GPIO17)
SCK: D10.1, J1.13, J4.P5 (CLK), R7.1, TP8.TP, U1.6 (CLK), U2.6 (IO6)
SCL: J3.4, R2_PINH.1, SENSOR2.4 (SCK), U2.20 (IO22), U3.16 (SCL), U4.7 (SCL)
SDA: J3.3, R1_PINH.1, SENSOR2.3 (SDI), U2.19 (IO21), U3.15 (SDA), U4.8 (SDA)
SRC: C4.2, D5.2 (A), L1.1, Q3.3 (D)
SS_SD: D6.1, J4.P2 (CD/DAT3), R10.1, U2.4 (IO4)
TX: TP1.TP, U2.25 (TXD0/GPIO16)
USB_D+: D1.1 (I/O1_1), U2.14 (IO13)
USB_D-: D1.3 (I/O2_1), U2.13 (IO12)
VBAT: C2_BAT.1, MCP73831.3 (VBAT), Q1.3 (D), TP3.TP, U4.2 (CELL), U4.3 (VDD)
VBUS: C1_BAT.1, C4_USB.1, C5_USB.1, CHG_LED.A, D1.5 (VBUS), D2.2 (ANODE), MCP73831.4 (VIN), PFMF.050.1.2, Q1.1 (G), R1_PWRUSB.1, TP14.TP
VRTC: C8.1, C10_SUPERCAP.2, R_CAPACITOR.1, U3.14 (VBAT)
VUSB: J2.A4, J2.A9, J2.B4, J2.B9, PFMF.050.1.1

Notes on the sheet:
USB C connector & ESD protection
LDO Voltage Regulator
SD0805S020S1R0
DMG2305UX-7
SD Card
Display Type Selector
E-Paper Drive Circuit
Li-Po Battery Charging Controller
ESP36 C6
E-Paper Display Header
EPD Power
Environmental Sensor BME688
Voltage Supervisor + Reset &
Boot / IO Button
Battery Charge Level
RTC Module DS3231SN
Test Pads
Qwiic /
Stemma QT
SPI ESD Protection Lines
External NOR Flash 64MB
OpenBook Schematic

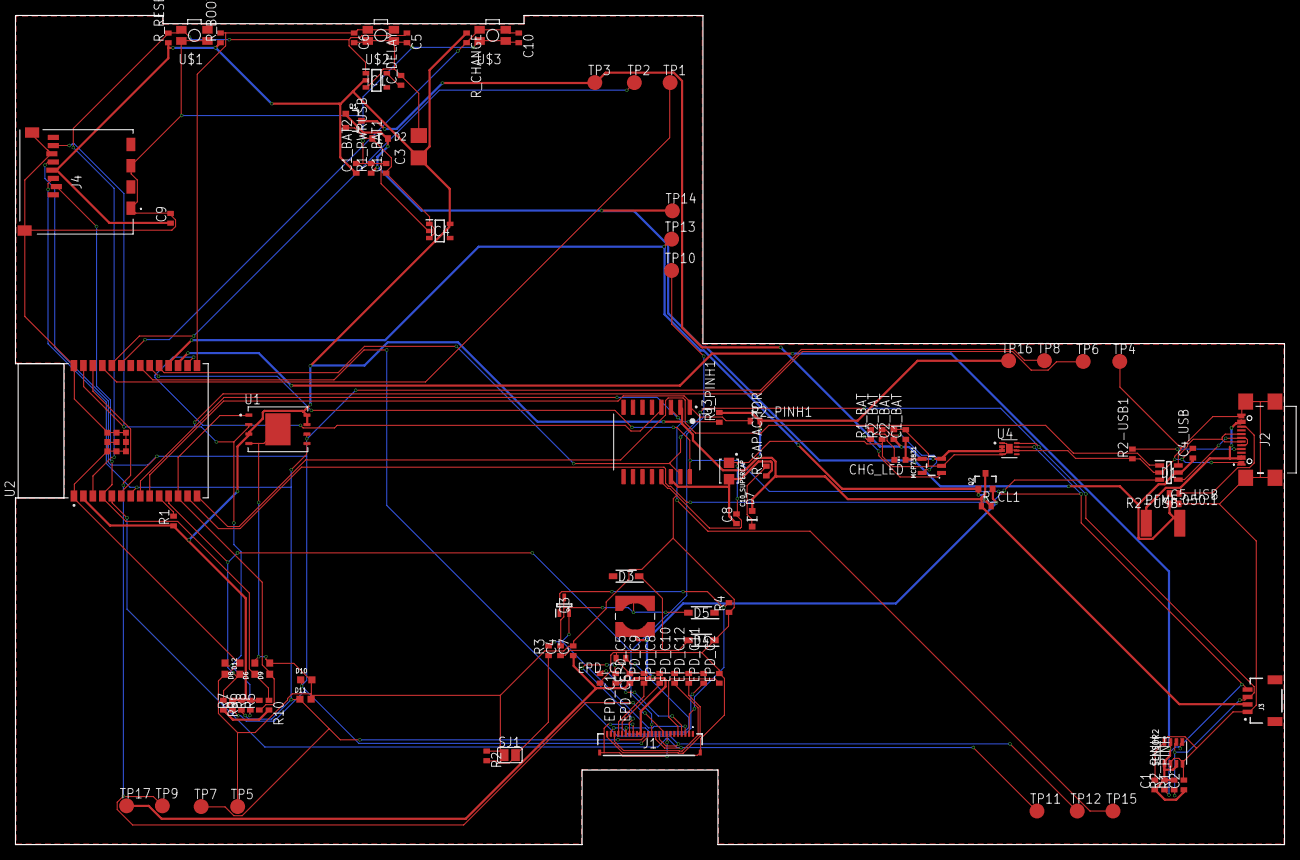
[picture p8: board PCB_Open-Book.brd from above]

Board: 2 copper layers, 170.2 x 111.2 mm, 103 parts (0 on the bottom side), 55 nets.

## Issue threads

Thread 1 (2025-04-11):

Schematic Names

pachirishu, 2025-04-11:
În fișierul tău schematic apar câteva nume în plus

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
Aici nu ar trebui să apară "SAMACSYS..."

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
Totodată aici denumirile la butoane nu sunt puse corect, iar în PCB apare mai apoi U$1, U$2, respectiv U$3

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

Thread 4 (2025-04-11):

Grosime PCB

pachirishu, 2025-04-11:
Placa are grosimea de 1.6mm, iar aceasta ar trebui să fie de 1mm

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

Pentru rezolvare, intri pe fila Rules, selectezi "Layer Stack", apeși pe "Edit material properties" și apoi selectezi 1.6 și scrii 1

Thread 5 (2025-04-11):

Numele pe silkscreen

pachirishu, 2025-04-11:
Numele de pe silkscreen nu sunt vizibile toate

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

Recomandare, mută numele care apar în piese, poți încerca să mai distanțezi piese dacă nu e loc între ele sau poți să faci unele nume mai mici ca să poată intra
Pe această imagine, recomand să cobori numele cât să nu mai intre peste piese și să scoți în afară D_-urile, Q3 și J1

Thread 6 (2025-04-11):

PCB Overall

pachirishu, 2025-04-11:
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

Ai anumite spații goale rămase în PCB care apar cu negru, ar fi bine să fie cât mai puține, astfel ai putea să adaugi câteva vias-uri și apoi să le tragi un contur. Dacă ai folosit via stitching, aceasta nu se salvează în fișierele cu extensia .brd, doar .fbrd și din acest motiv nu îmi apare nici dacă ai folosit lângă modulul ESP32 cum se recomandă la punctul 6: Aplicați Via Stitching între cele două planuri de masă, în special în preajma modulului ESP32.

Totodată, ai putea să ai pe margine dimensiunile pentru a ajuta la observarea corectă a plăcuței dacă e în parametri

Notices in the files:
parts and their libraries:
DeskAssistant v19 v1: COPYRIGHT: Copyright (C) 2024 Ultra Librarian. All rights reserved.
